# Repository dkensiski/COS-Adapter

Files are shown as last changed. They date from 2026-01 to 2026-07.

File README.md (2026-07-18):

# COS Adapter V2

The [Kenwood TK-981](https://www.kw902.com/981generalinfo.html) radio's COS output
does not go suffciently low to reliably trigger the
[Arcom RC210](https://www.arcomcontrollers.com/index.php?Itemid=524&route=product/product&product_id=33)
controller's COS input, so Jim (K6KCP) designed this comparator circuit to perform
the trick.

## Features

* Trigger pot to adjust the COS trigger level
* Relay to close COS outut (normally open)
* Audio circuitry (thanks Steve W6KCS) to adjust and filter the audio between
  the devices.  Components can be added or jumpered to suit.
* Mounting holes for a small [project box](https://amazon.com/dp/B07D23C962/)
  or inside the [RC210 enclosure](https://www.arcomcontrollers.com/index.php?Itemid=524&route=product/product&product_id=32)

## Parts list

| Part | Value | Notes |
| --- | ----- | ----- |
| **C1** | .01 | |
| **D1** | LED | |
| **D2** | 1N400X | |
| **J1** | 2-pin JMT male | |
| **J2** | 2-pin JMT male | |
| **J3** | RCA phono | Cliff FC68400, Same Sky RCJ-02x, or equiv |
| **J8** | 3-pin JMT male | |
| **J9** | 3-pin JMT male | |
| **K1** | DIP Mini Relay | Littlefuse HE721C1200 |
| **Q1** | 2N3906 | |
| **R1** | 4700 ohm | |
| **R2** | 1000 ohm | |
| **R3** | 50K | optional; replace with wire if not used |
| **R4** | 50K | optional; replace with wire if not used |
| **RV1** | 50K trim pot | Bourns style 3386P or 3386V |
| **RV2** | 10K trim pot | |
| **RV3** | 10K trim pot | |
| **U1** | LM741 | |

## 3-D rendering

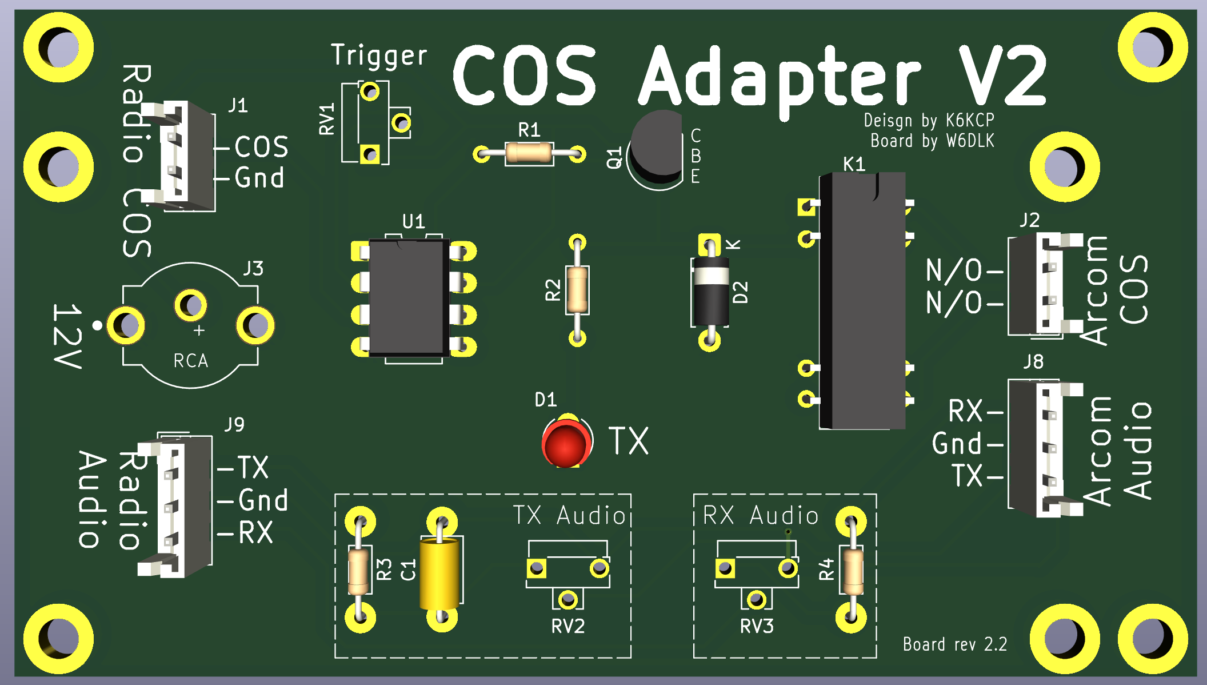
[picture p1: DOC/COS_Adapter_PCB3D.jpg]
PCB v1.0 3D rendering


## PCB Layout

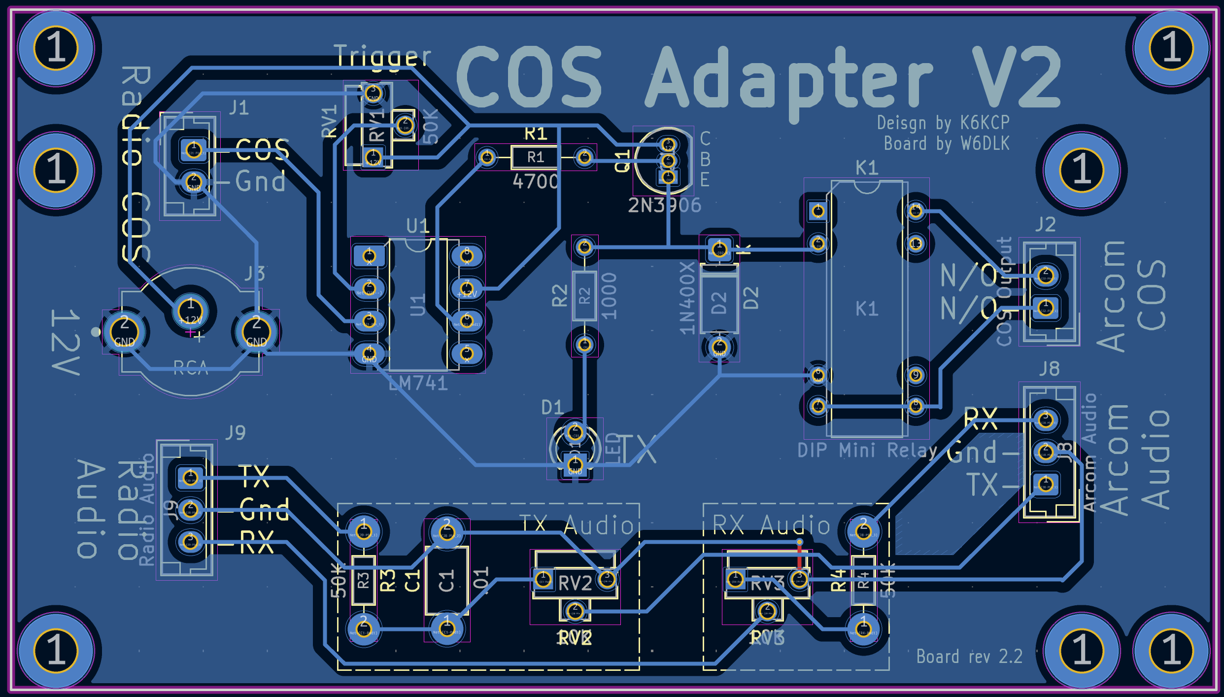
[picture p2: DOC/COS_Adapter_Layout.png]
PCB v1.0 layout


## Schematic

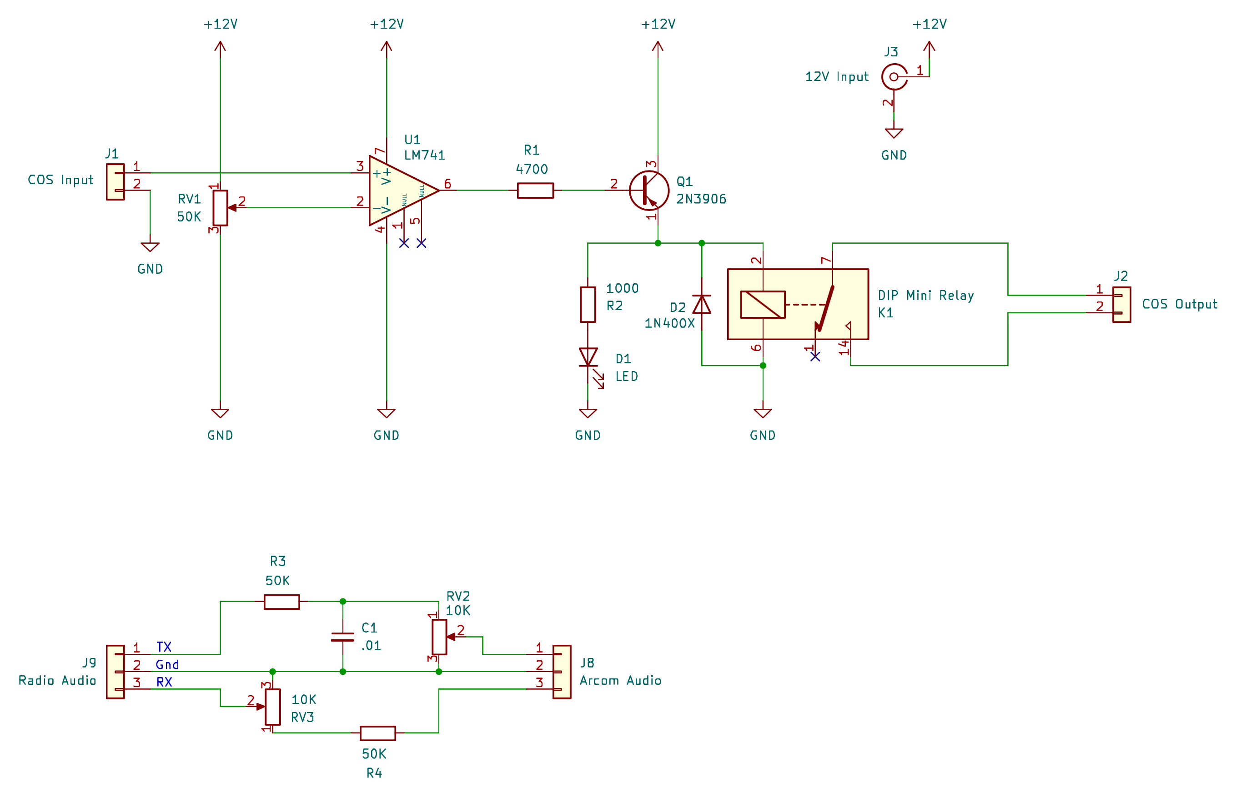
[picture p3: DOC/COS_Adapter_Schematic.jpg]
Schematic v1.0


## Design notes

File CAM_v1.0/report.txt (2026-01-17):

Warning: Width correction constrained.  The width correction value must be in the range of [0.000001 mm; 0.199999 mm] for the current design rules.
Plotted to '/Users/dlk/Desktop/Kenwood Repeater/COS Adapter V2/COS Adapter V2-F_Cu.gbr'.
Plotted to '/Users/dlk/Desktop/Kenwood Repeater/COS Adapter V2/COS Adapter V2-B_Cu.gbr'.
Plotted to '/Users/dlk/Desktop/Kenwood Repeater/COS Adapter V2/COS Adapter V2-F_Paste.gbr'.
Plotted to '/Users/dlk/Desktop/Kenwood Repeater/COS Adapter V2/COS Adapter V2-B_Paste.gbr'.
Plotted to '/Users/dlk/Desktop/Kenwood Repeater/COS Adapter V2/COS Adapter V2-F_Silkscreen.gbr'.
Plotted to '/Users/dlk/Desktop/Kenwood Repeater/COS Adapter V2/COS Adapter V2-B_Silkscreen.gbr'.
Plotted to '/Users/dlk/Desktop/Kenwood Repeater/COS Adapter V2/COS Adapter V2-F_Mask.gbr'.
Plotted to '/Users/dlk/Desktop/Kenwood Repeater/COS Adapter V2/COS Adapter V2-B_Mask.gbr'.
Plotted to '/Users/dlk/Desktop/Kenwood Repeater/COS Adapter V2/COS Adapter V2-Edge_Cuts.gbr'.
Created Gerber job file '/Users/dlk/Desktop/Kenwood Repeater/COS Adapter V2/COS Adapter V2-job.gbrjob'.
Info: Done.
Plotted to '/Users/dlk/Desktop/Kenwood Repeater/COS Adapter V2/Fabrication/COS Adapter V2-F_Cu.gbr'.
Plotted to '/Users/dlk/Desktop/Kenwood Repeater/COS Adapter V2/Fabrication/COS Adapter V2-B_Cu.gbr'.
Plotted to '/Users/dlk/Desktop/Kenwood Repeater/COS Adapter V2/Fabrication/COS Adapter V2-F_Paste.gbr'.
Plotted to '/Users/dlk/Desktop/Kenwood Repeater/COS Adapter V2/Fabrication/COS Adapter V2-B_Paste.gbr'.
Plotted to '/Users/dlk/Desktop/Kenwood Repeater/COS Adapter V2/Fabrication/COS Adapter V2-F_Silkscreen.gbr'.
Plotted to '/Users/dlk/Desktop/Kenwood Repeater/COS Adapter V2/Fabrication/COS Adapter V2-B_Silkscreen.gbr'.
Plotted to '/Users/dlk/Desktop/Kenwood Repeater/COS Adapter V2/Fabrication/COS Adapter V2-F_Mask.gbr'.
Plotted to '/Users/dlk/Desktop/Kenwood Repeater/COS Adapter V2/Fabrication/COS Adapter V2-B_Mask.gbr'.
Plotted to '/Users/dlk/Desktop/Kenwood Repeater/COS Adapter V2/Fabrication/COS Adapter V2-Edge_Cuts.gbr'.
Created Gerber job file '/Users/dlk/Desktop/Kenwood Repeater/COS Adapter V2/Fabrication/COS Adapter V2-job.gbrjob'.
Info: Done.
Info: Done.
Info: Done.

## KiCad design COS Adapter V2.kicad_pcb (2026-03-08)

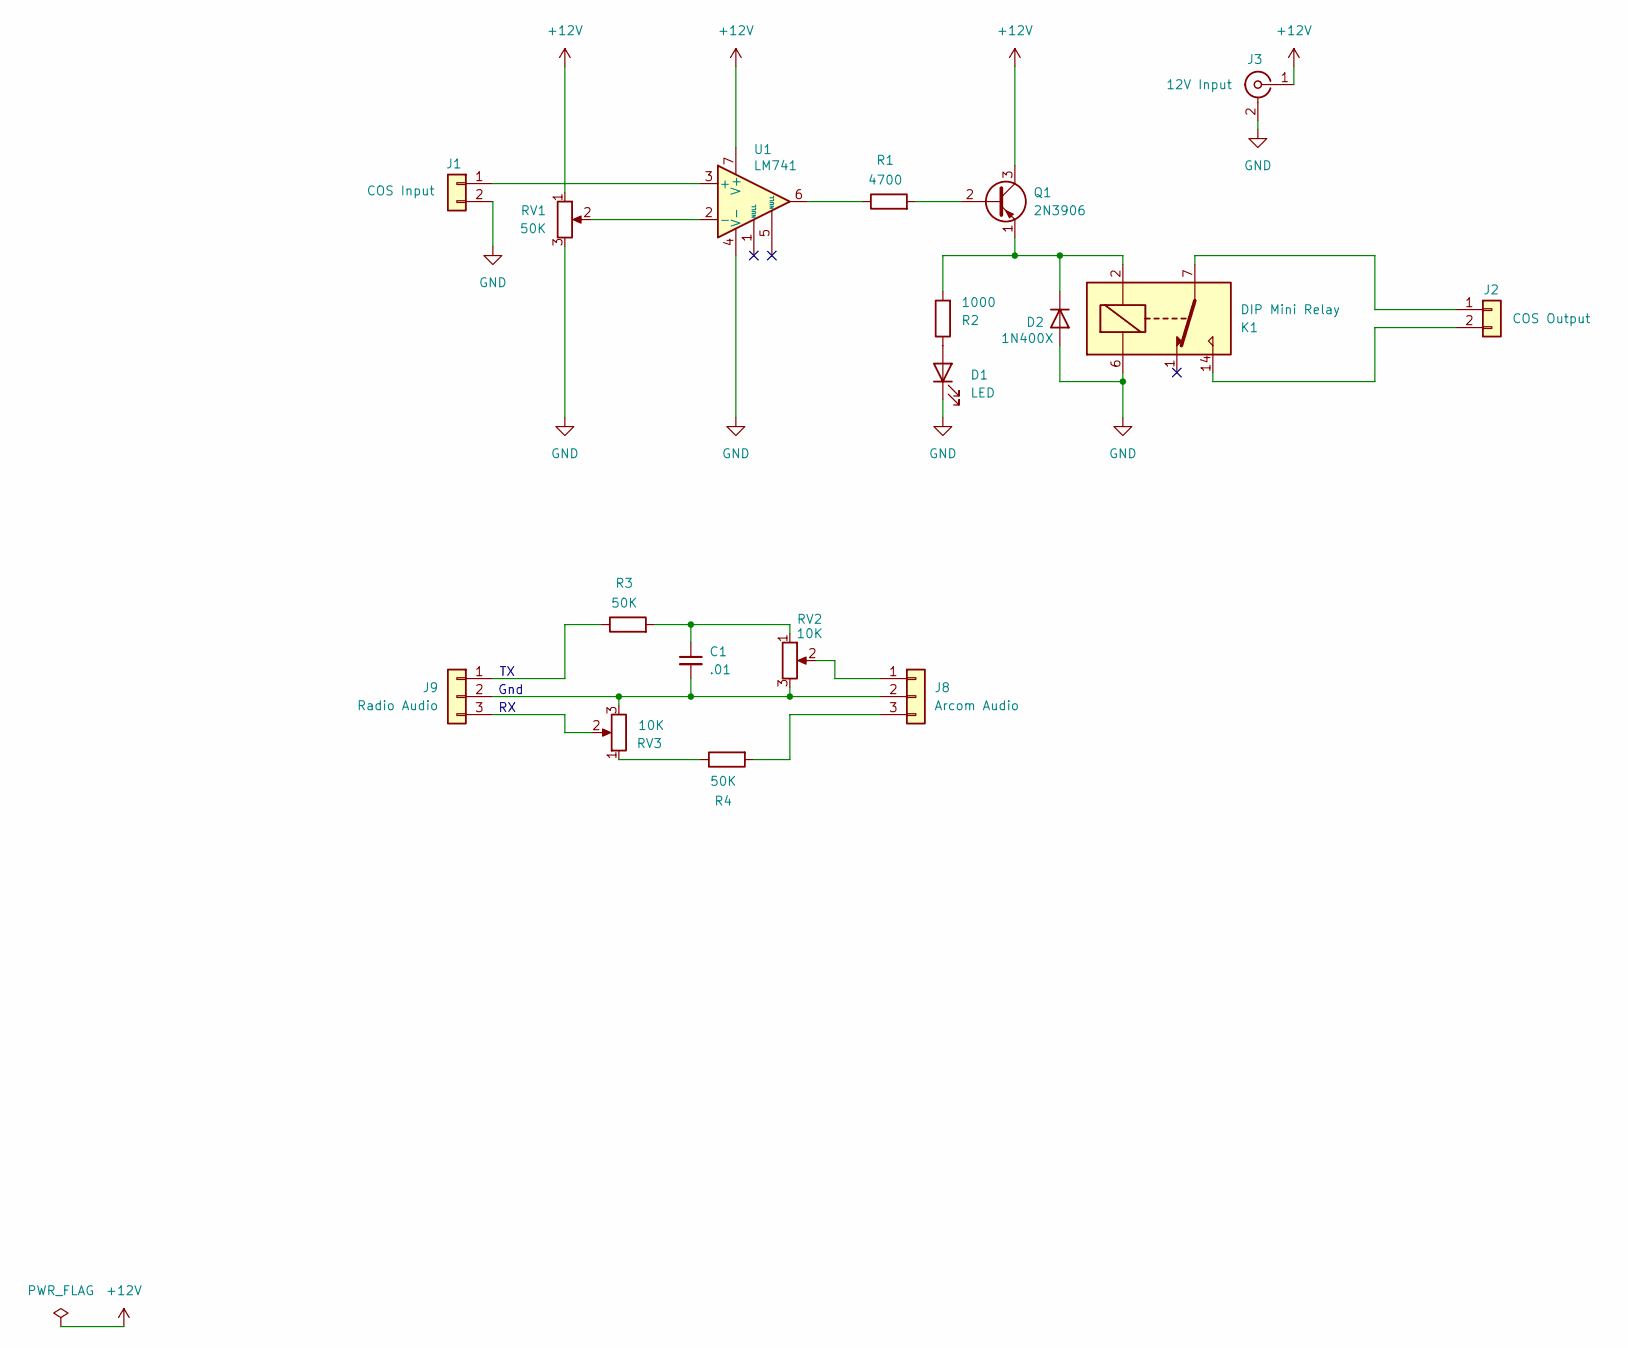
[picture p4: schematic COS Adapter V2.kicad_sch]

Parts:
C1: .01; C_Axial_L5.1mm_D3.1mm_P7.50mm_Horizontal_BIG_FEET
D1: LED; LED_D3.0mm
D2: 1N400X; D_A-405_P7.62mm_Horizontal
J1: COS Input; JST_EH_B2B-EH-A_1x02_P2.50mm_Vertical
J2: COS Output; JST_EH_B2B-EH-A_1x02_P2.50mm_Vertical
J3: 12V Input; CUI_RCJ-025
J8: Arcom Audio; JST_EH_B3B-EH-A_1x03_P2.50mm_Vertical
J9: Radio Audio; JST_EH_B3B-EH-A_1x03_P2.50mm_Vertical
K1: DIP Mini Relay; Relay_StandexMeder_DIP_LowProfile
Q1: 2N3906; TO-92_Inline
R1: 4700; R_Axial_DIN0204_L3.6mm_D1.6mm_P7.62mm_Horizontal
R2: 1000; R_Axial_DIN0204_L3.6mm_D1.6mm_P7.62mm_Horizontal
R3, R4: 50K; R_Axial_DIN0204_L3.6mm_D1.6mm_P7.62mm_Horizontal_BIG_FEET
RV1: 50K; Potentiometer_Runtron_RM-063_Horizontal
RV2, RV3: 10K; Potentiometer_Runtron_RM-063_Horizontal
U1: LM741; DIP-8_W7.62mm_LongPads

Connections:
+12V: J3.1 (In), Q1.3 (C), RV1.1, U1.7 (V+)
GND: D1.1 (K), D2.2 (A), J1.2, J3.2 (Ext), K1.6, RV1.3, U1.4 (V-)
unnamed: C1.1, R3.2, RV2.1
unnamed: D1.2 (A), R2.1
unnamed: D2.1 (K), K1.2, Q1.1 (E), R2.2
unnamed: J1.1, U1.3 (+)
unnamed: J2.1, K1.7, K1.8
unnamed: J2.2, K1.14
unnamed: J8.1, RV2.2
unnamed: C1.2, J8.2, J9.2, RV2.3, RV3.3
unnamed: J8.3, R4.2
unnamed: J9.1, R3.1
unnamed: J9.3, RV3.2
unnamed: Q1.2 (B), R1.2
unnamed: R1.1, U1.6
unnamed: R4.1, RV3.1
unnamed: RV1.2, U1.2 (-)

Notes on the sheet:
Gnd

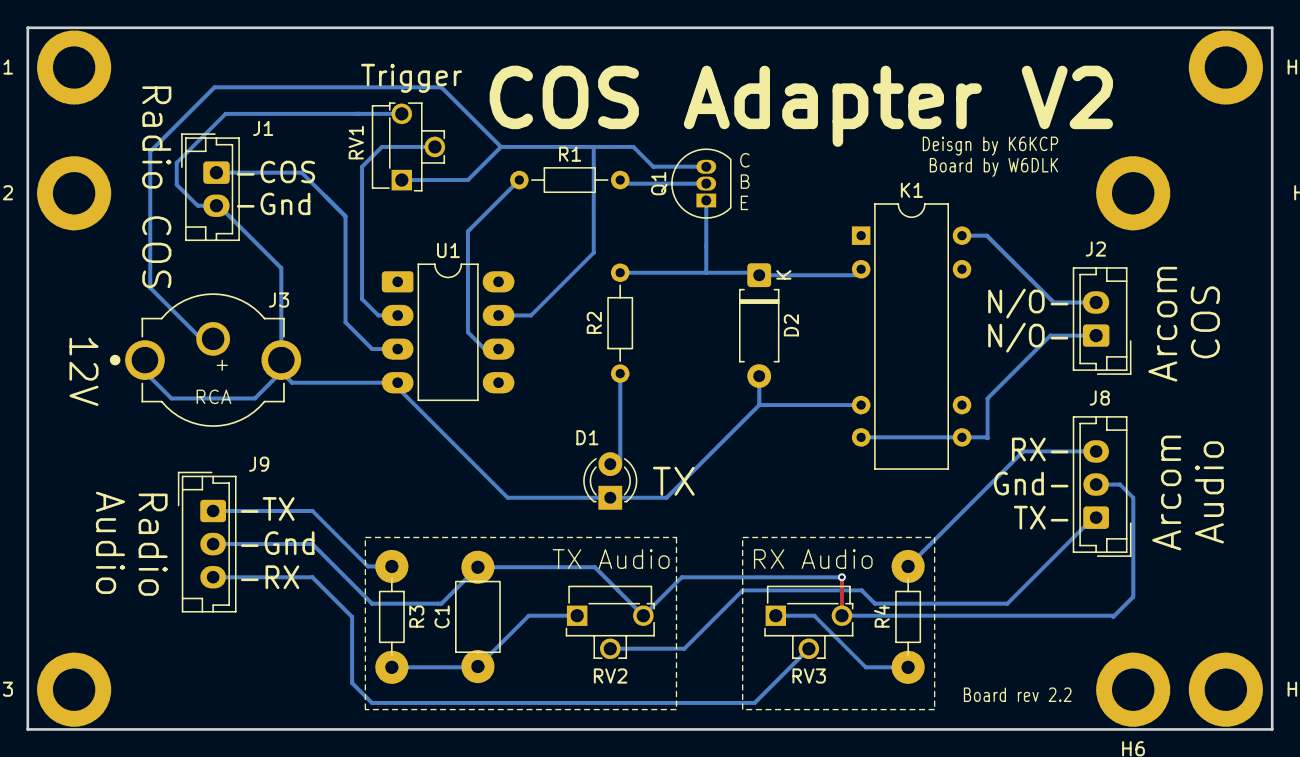
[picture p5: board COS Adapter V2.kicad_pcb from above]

Board: 2 copper layers, 94.0 x 53.0 mm, 25 parts (0 on the bottom side), 17 nets.

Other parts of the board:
H1, H2, H3, H4, H5, H6, H7: MountingHole_3.2mm_M3_DIN965_Pad

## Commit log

2026-01-13 added big pads
    [COS Adapter V2.kicad_pcb, COS Adapter V2.kicad_sch]
2026-01-14 add Arcom mounting holes
    [COS Adapter V2.kicad_pcb, COS Adapter V2.kicad_sch]
2026-01-17 fabrication export for v1.0 board
    [COS Adapter V2-B_Cu.gbr, COS Adapter V2-B_Mask.gbr, COS Adapter V2-B_Paste.gbr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]
2026-01-17 fill in the foil
    [COS Adapter V2.kicad_pcb]
2026-03-08 v2.2: fix diode polarity
    [COS Adapter V2.kicad_pcb, COS Adapter V2.kicad_sch]
